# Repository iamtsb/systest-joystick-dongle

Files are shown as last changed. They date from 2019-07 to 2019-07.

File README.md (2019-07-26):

# Joystick test dongle for Amiga Test Kit (Systest)

current version: v1.1

release date: 2019-07-26

### Why ?

I’m repairing lots of Amiga machines, and my (original) joystick connectors where failing after they have been swapped between all those machines. So that’s why I designed this dongle ( and ofcourse i’m a bit lazy to handle the joystick each time!)

### How does it works

This dongle simulates Up, Right, Down, Left, Button1, Button2, Button3.
There is an interval of approx. 1 second between the simulated actions of the “joystick”.

### More information

see: https://www.tsb.space/projects/systest-joystick-dongle/

download systest:  [Systest ( amiga ) from Keir Fraser](https://github.com/keirf/Amiga-Stuff) ( [download](https://drive.google.com/file/d/0B6F45EdkSMp1ZGhXMWRvOXVDd3M/view) ).

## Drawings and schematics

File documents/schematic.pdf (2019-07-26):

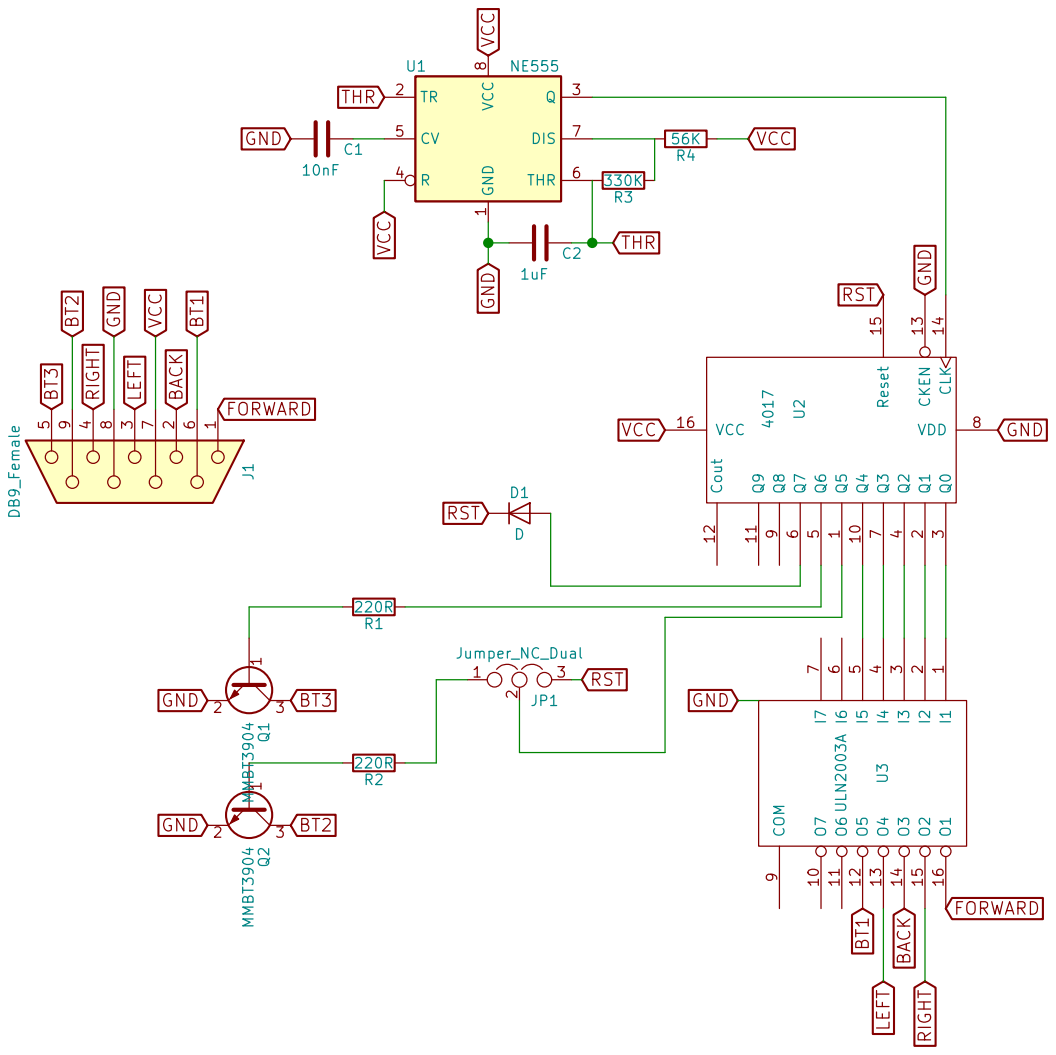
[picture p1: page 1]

File: joystick tester systest.sch Sheet: / TSB GND

1 Q4 10 Q9 11 Cout 12 CKEN 13 CLK 14 Reset 15 VCC 16 Q1

Id: 1/1 Title: SYSTEST JOYSTICK TEST DONGLE

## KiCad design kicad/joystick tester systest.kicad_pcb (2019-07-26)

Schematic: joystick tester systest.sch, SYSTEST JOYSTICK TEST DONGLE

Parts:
C1: 10nF; C_0805_HandSoldering
C2: 1uF; C_0805_HandSoldering
D1: D; D_SOD-123
J1: DB9_Female; DB9F_CI
JP1: Jumper_NC_Dual; Pin_Header_Straight_1x03_Pitch1.27mm
Q1, Q2: MMBT3904; SOT-23
R1, R2: 220R; R_0805_HandSoldering
R3: 330K; R_0805_HandSoldering
R4: 56K; R_0805_HandSoldering
U1: NE555; SOIC-8_3.9x4.9mm_Pitch1.27mm
U2: 4017; SO-16-N
U3: ULN2003A; SO-16-N

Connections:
BACK: J1.2, U3.14 (O3)
BT1: J1.6, U3.12 (O5)
BT2: J1.9, Q2.3 (C)
BT3: J1.5, Q1.3 (C)
FORWARD: J1.1, U3.16 (O1)
GND: C1.2, C2.2, J1.8, Q1.2 (E), Q2.2 (E), U1.1 (GND), U2.8 (VDD), U2.13 (CKEN), U3.8 (GND)
LEFT: J1.3, U3.13 (O4)
unnamed: C1.1, U1.5 (CV)
unnamed: D1.2, U2.6 (Q7)
unnamed: JP1.1, R2.1
unnamed: JP1.2, U2.1 (Q5)
unnamed: Q1.1 (B), R1.2
unnamed: Q2.1 (B), R2.2
unnamed: R1.1, U2.5 (Q6)
unnamed: R3.1, R4.2, U1.7 (DIS)
unnamed: U1.3 (Q), U2.14 (CLK)
unnamed: U2.2 (Q1), U3.2 (I2)
unnamed: U2.3 (Q0), U3.1 (I1)
unnamed: U2.4 (Q2), U3.3 (I3)
unnamed: U2.7 (Q3), U3.4 (I4)
unnamed: U2.10 (Q4), U3.5 (I5)
RIGHT: J1.4, U3.15 (O2)
RST: D1.1, JP1.3, U2.15 (Reset)
THR: C2.1, R3.2, U1.2 (TR), U1.6 (THR)
VCC: J1.7, R4.1, U1.4 (R), U1.8 (VCC), U2.16 (VCC)

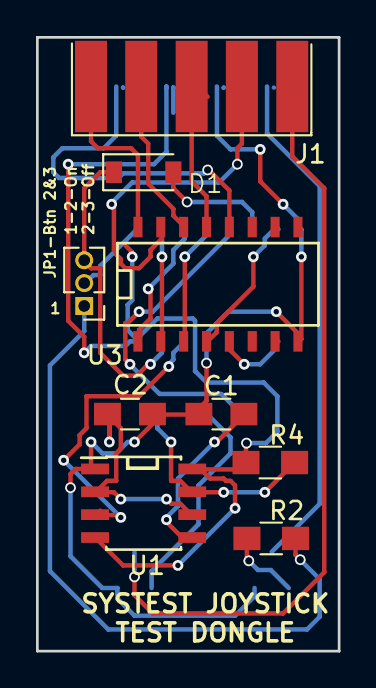
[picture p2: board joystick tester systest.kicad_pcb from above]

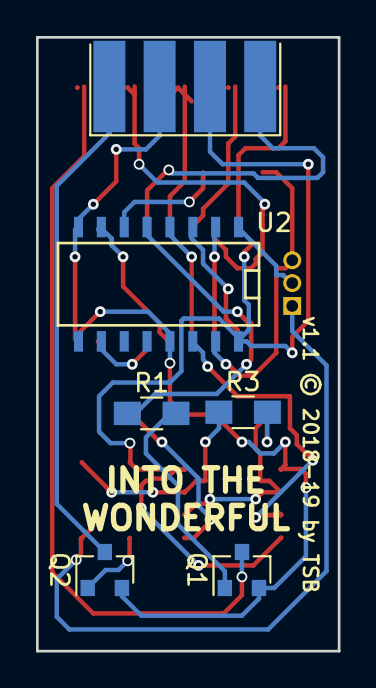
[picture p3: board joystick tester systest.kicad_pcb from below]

Board: 2 copper layers, 16.8 x 34.1 mm, 14 parts (5 on the bottom side), 25 nets.

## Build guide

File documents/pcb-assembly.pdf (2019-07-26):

## SYSTEST-JOYSTICK DONGLE - PCB Assembly

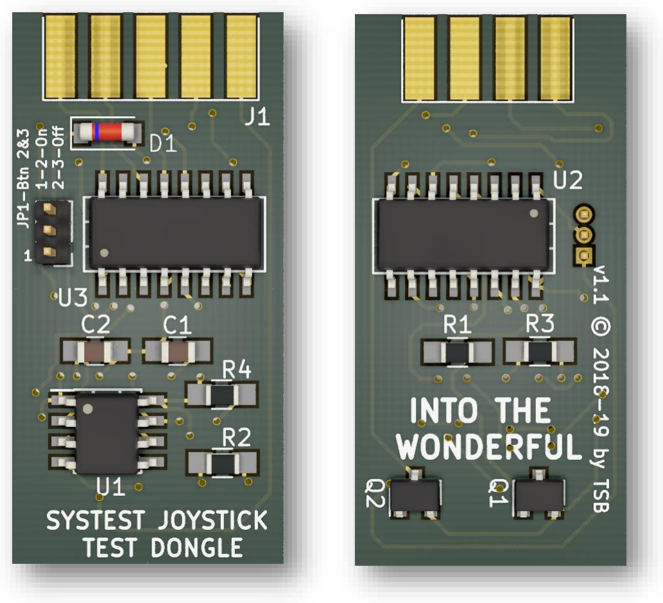
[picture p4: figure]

Project: SYSTEST-JOYSTICK-DONGLE Version: 1.1, release: 26-7-2019

PCB components

label | Component/value | Package | Description
U1 | NE555 | SIOC-8 | Timer
U2 | CD4017 | SIOC-16 | 10 bit counter
U3 | ULN2003A | SIOC-16 | Darlington Transistor Arrays
R1 | 220R | 0805 | Resistor
R2 | 220R | 0805 | Resistor
R3 | 330K | 0805 | Resistor
R4 | 56K | 0805 | Resistor
C1 | 10nF | 0805 | Capacitor
C2 | 1uF | 0805 | Capacitor
D1 | 1N4148 | SOD-123 | Diode
Q1 | MMBT3904 | SOT-23 | Transistor NPN
Q2 | MMBT3904 | SOT-23 | Transistor NPN
JP1 | 1x03p header | | Pin Header pitch 1,27mm
J1 | DB9F | DB9F | d-sub 9 pin female connector

Solder all components onto the board, I advise to solder J1 as last component.

## SYSTEST-JOYSTICK DONGLE - PCB Assembly

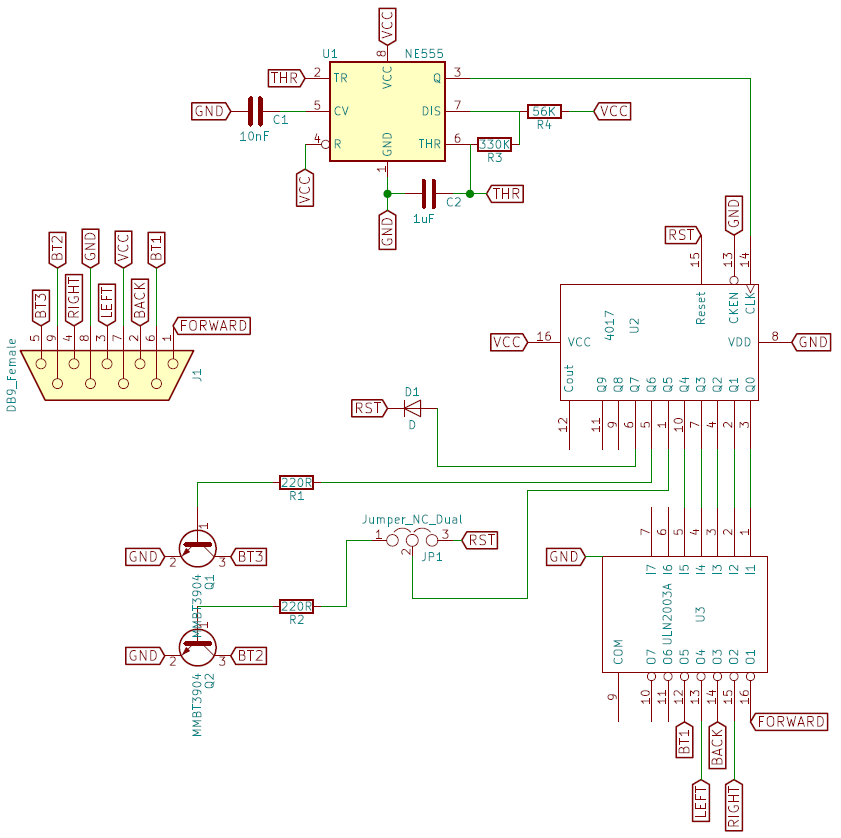
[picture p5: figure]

Project: SYSTEST-JOYSTICK-DONGLE Version: 1.1, release: 26-7-2019

Schematic

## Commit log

2019-07-26 init version
    [joystick tester systest.kicad_pcb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]
2019-07-26 update
    -updated pcb file with 3d models
    -added build manual
    [joystick tester systest.kicad_pcb]

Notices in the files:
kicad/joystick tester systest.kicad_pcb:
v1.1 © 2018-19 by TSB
